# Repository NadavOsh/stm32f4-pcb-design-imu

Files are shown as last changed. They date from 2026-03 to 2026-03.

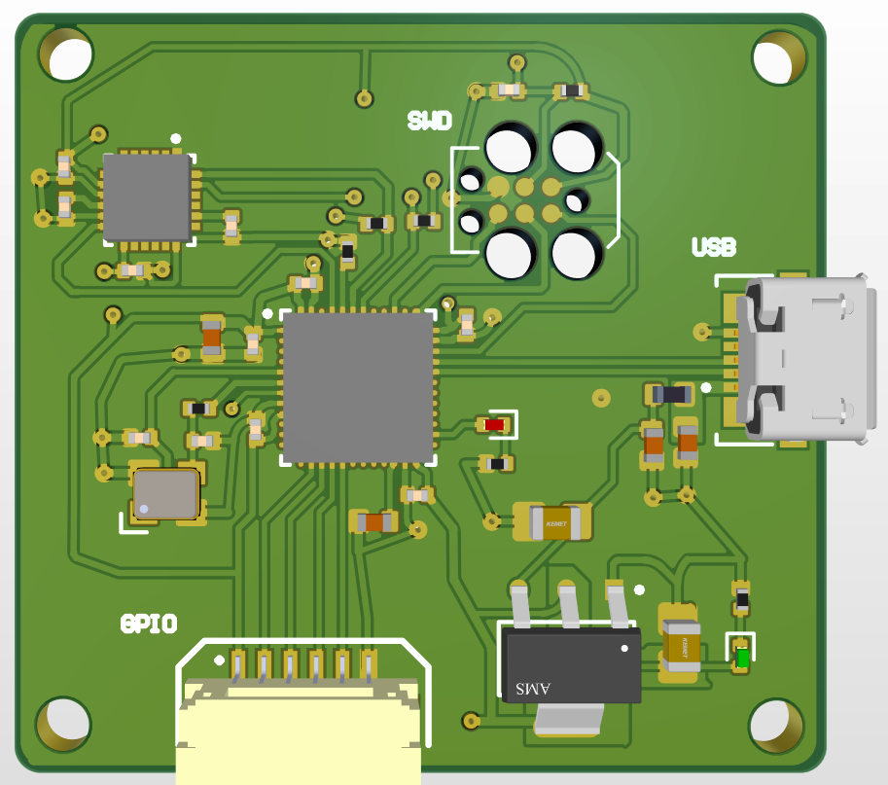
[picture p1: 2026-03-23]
Docs/STM32_PCB.png

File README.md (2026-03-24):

# stm32f4-pcb-design-imu
Custom STM32F4-based 4-layers PCB featuring MPU-6050 IMU, USB power, LDO regulation, and SWD debugging





# 1. Overview

This board is a custom embedded system built around the STM32F4 microcontroller, designed for motion sensing applications using an onboard IMU.

It includes:

* MCU: STM32F4 series (High-performance ARM Cortex-M4).

* Sensors: IMU MPU-6050 6-Axis Gyroscope & Accelerometer. Connected via I2C.

* Micro USB (Molex 473460001).
 
* Onboard AMS1117-3.3 LDO (5V to 3.3V regulation).

* JST-GH 6-pin (SM06B-GHS-TB) for external peripherals.

* Programming: Tag-Connect TC2030 (Plug-of-Nails™) SWD debugging interface.

* Configuration: BOOT0 hardwired to GND for normal flash boot.

# 2. Hardware Architecture

## Core Components:

## MCU: STM32F4 series
* IMU: MPU-6050 (accelerometer + gyroscope)

*Voltage Regulator: AMS1117-3.3 (5V → 3.3V)

*Clock Source: External 24 MHz oscillator

## Power System:
* Input: 5V via USB connector (473460001)
* Regulation: AMS1117-3.3 LDO
* Output: 3.3V rail powering MCU and peripherals

## Interfaces:
* USB
* SWD Debugging:
  * Connector: TC2030 Tag-Connect
  * Signals:
     * SWDIO
     * SWCLK
     * GND
    * 3.3V (reference)

## IMU Interface (MPU-6050):
* Communication: I2C
* Pull-up resistors: Present on SDA and SCL lines
* Powered from 3.3V rail

## Expansion Connector:
* JST 6-pin connector (SM06B-GHS-TB)
* Can be used for:
    * External sensors
    * UART / I2C / GPIO expansion

# 3. Boot Configuration:

* BOOT0 is tied to GND
   * MCU always boots from internal Flash
   * Prevents accidental boot into system bootloader

# 4. Clock Configuration:

* External 24 MHz oscillator connected to MCU

# 5. Pin Mapping

## Pin Mapping

| Function | MCU Pin | Direction | Description |
|---|---|---|---|
| I2C_SCL | PB6 | Bidir | I2C clock to MPU-6050 (pull-up) |
| I2C_SDA | PB7 | Bidir | I2C data to MPU-6050 (pull-up) |
| USB_VBUS | - | Input | 5V input from USB connector |
| USB_DN | PA11 | Bidir | USB differential data (-) |
| USB_DP | PA12 | Bidir | USB differential data (+) |
| SWDIO | PA13 | Bidir | SWD debug data |
| SWCLK | PA14 | Bidir | SWD debug clock |
| SW0 | PB3 | Bidir | Serial Wire Output. Debug |
| LED | PB13 | Output | Red LED |
| NRST | NRST | Input | MCU negative reset |
| BOOT0 | BOOT0  | Input | Boot configuration (Flash mode) |
| HSE_IN | PH0 | Input | External 24 MHz oscillator input |
| HSE_OUT | PH1 | Output | External oscillator output |
| 3V3 | — | Power | Regulated 3.3V rail |
| GND | — | Ground | Ground |
| JST_PIN_1 | - | Power | 3.3V |
| JST_PIN_2 | PA4 | I/O | Expansion connector |
| JST_PIN_3 | PA5 | I/O | Expansion connector |
| JST_PIN_4 | PA6 | I/O | Expansion connector |
| JST_PIN_5 | PA7 | I/O | Expansion connector |
| JST_PIN_6 | - | GND | GND |

# 6. Design Notes / Decisions

* Used I2C with pull-ups for reliable communication with IMU
* BOOT0 tied low for stable boot behavior
* Tag-Connect reduces connector footprint vs standard headers

# 7. Limitations / Future Improvements

* AMS1117 has high dropout and poor efficiency → consider switching regulator
* No ESD protection on USB

# 8. Files Included
* Schematic (PDF)
* PCB layout
* BOM
* Gerber Files
* Pick and Place

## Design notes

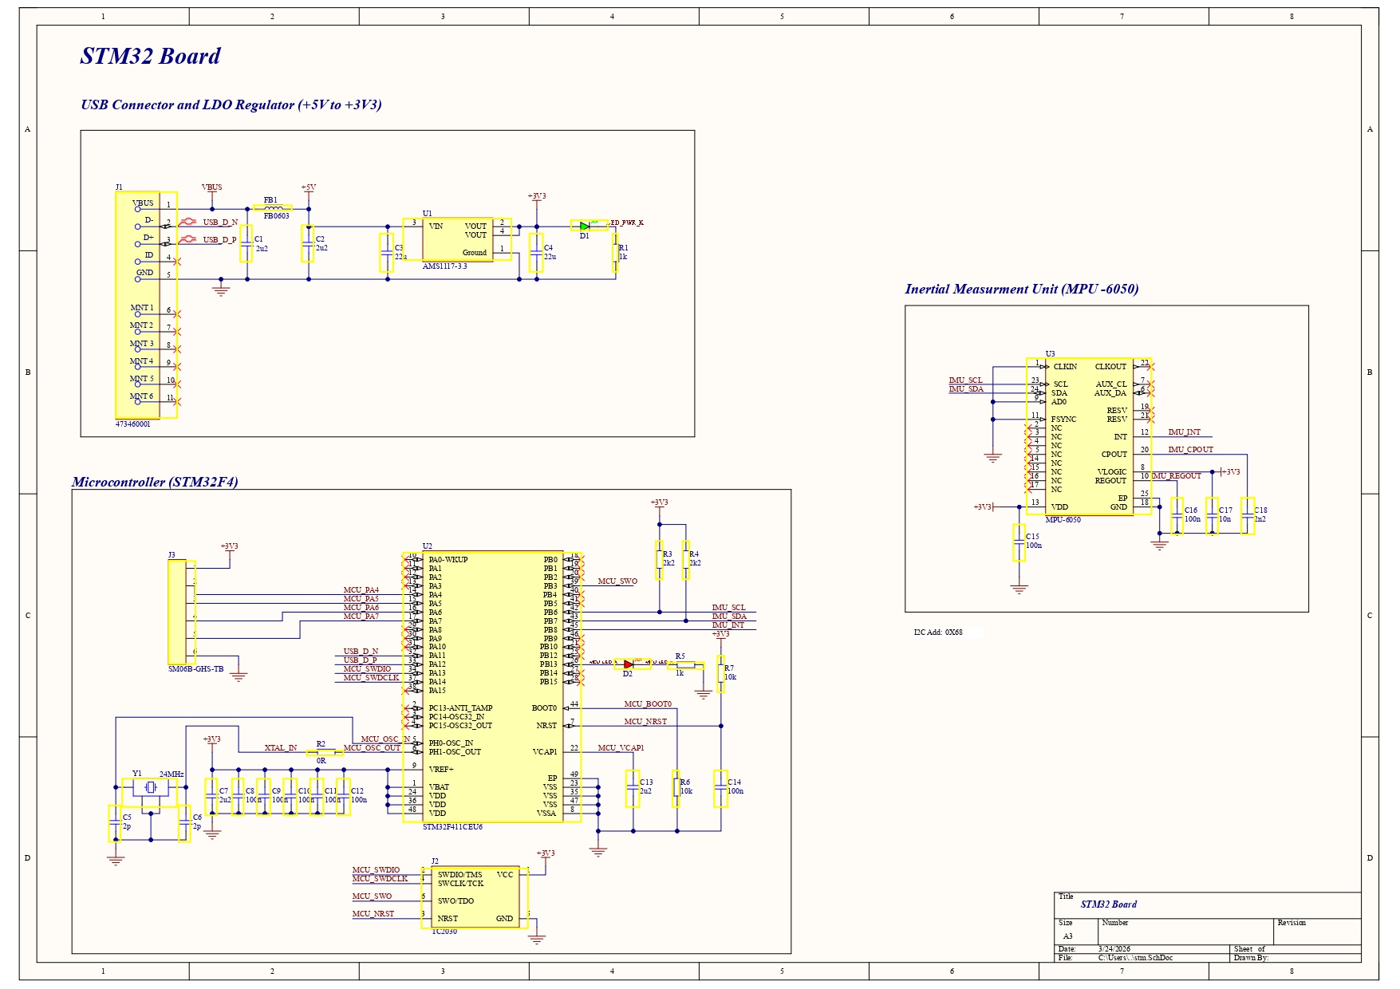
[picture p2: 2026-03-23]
Docs/STM32_Schematic_img.jpg

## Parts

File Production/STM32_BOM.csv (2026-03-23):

Comment | Description | Designator | Footprint | LibRef | Quantity
2u2 | Capacitor SMD 0603 | C1, C2, C7, C13 | CAP_0603 | CAP_0603 | 4
22u | Capacitor SMD 0805 | C3, C4 | CAP_0805 | CAP_0805 | 2
2p | Capacitor SMD 0402 | C5, C6 | CAP_0402 | CAP_0402 | 2
100n | Capacitor SMD 0402 | C8, C9, C10, C11, C12, C14, C15, C16 | CAP_0402 | CAP_0402 | 8
10n | Capacitor SMD 0402 | C17 | CAP_0402 | CAP_0402 | 1
2n2 | Capacitor SMD 0402 | C18 | CAP_0402 | CAP_0402 | 1
GREEN | LED 0402 GREEN SMD | D1 | LED_0402_GREEN | LED_0402_GREEN | 1
RED | LED 0402 RED SMD | D2 | LED_0402_RED | LED_0402_RED | 1
FB0603 | Ferrite Bead SMD 0603 | FB1 | FB_0603 | FB_0603 | 1
473460001 | CONN RCPT USB2.0 MICRO B SMD R/A | J1 | FP-473460001-MFG | CMP-2000-05246-2 | 1
SM06B-GHS-TB | Header Connector 6 Position 1.25MM Pitch SMD Horizontal JST GH | J3 | SM06B-GHS-TB | SM06B-GHS-TB | 1
1k | Resistor SMD 0402 | R1, R5 | RES_0402 | RES_0402 | 2
0R | Resistor SMD 0402 | R2 | RES_0402 | RES_0402 | 1
2k2 | Resistor SMD 0402 | R3, R4 | RES_0402 | RES_0402 | 2
10k | Resistor SMD 0402 | R6, R7 | RES_0402 | RES_0402 | 2
AMS1117-3.3 | LDO Voltage Regulators 1A, 3.3V | U1 | FP-AMS1117-IPC_C | CMP-209535-000001-1 | 1
STM32F411CEU6 | ARM Cortex-M4 32-bit MCU+FPU, 512 KB Flash, 128 KB RAM, 36 I/Os, 48-Pin UFQFPN, -40 to 85 degC, Tray | U2 | STM-UFQFPN48_L | CMP-0243-00165-1 | 1
MPU-6050 | 3-Axis Gyroscope, Accelerometer and a Digital Motion Processor(TM) (DMP), 2.375 to 3.46 V, -40 to 85 degC, 24-Pin QFN, RoHS, Tape and Reel | U3 | IS-QFN-24_V | CMP-1753-00002-2 | 1
24MHz | Crystal SMD 24MHz 10PPM 7pF 3225 | Y1 | XTAL_3225 | TSX-3225_24.0000MF15X-AC | 1

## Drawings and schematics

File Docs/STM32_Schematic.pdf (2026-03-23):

## USB Connector and LDO Regulator (+5V to +3V3)

# STM32 Board

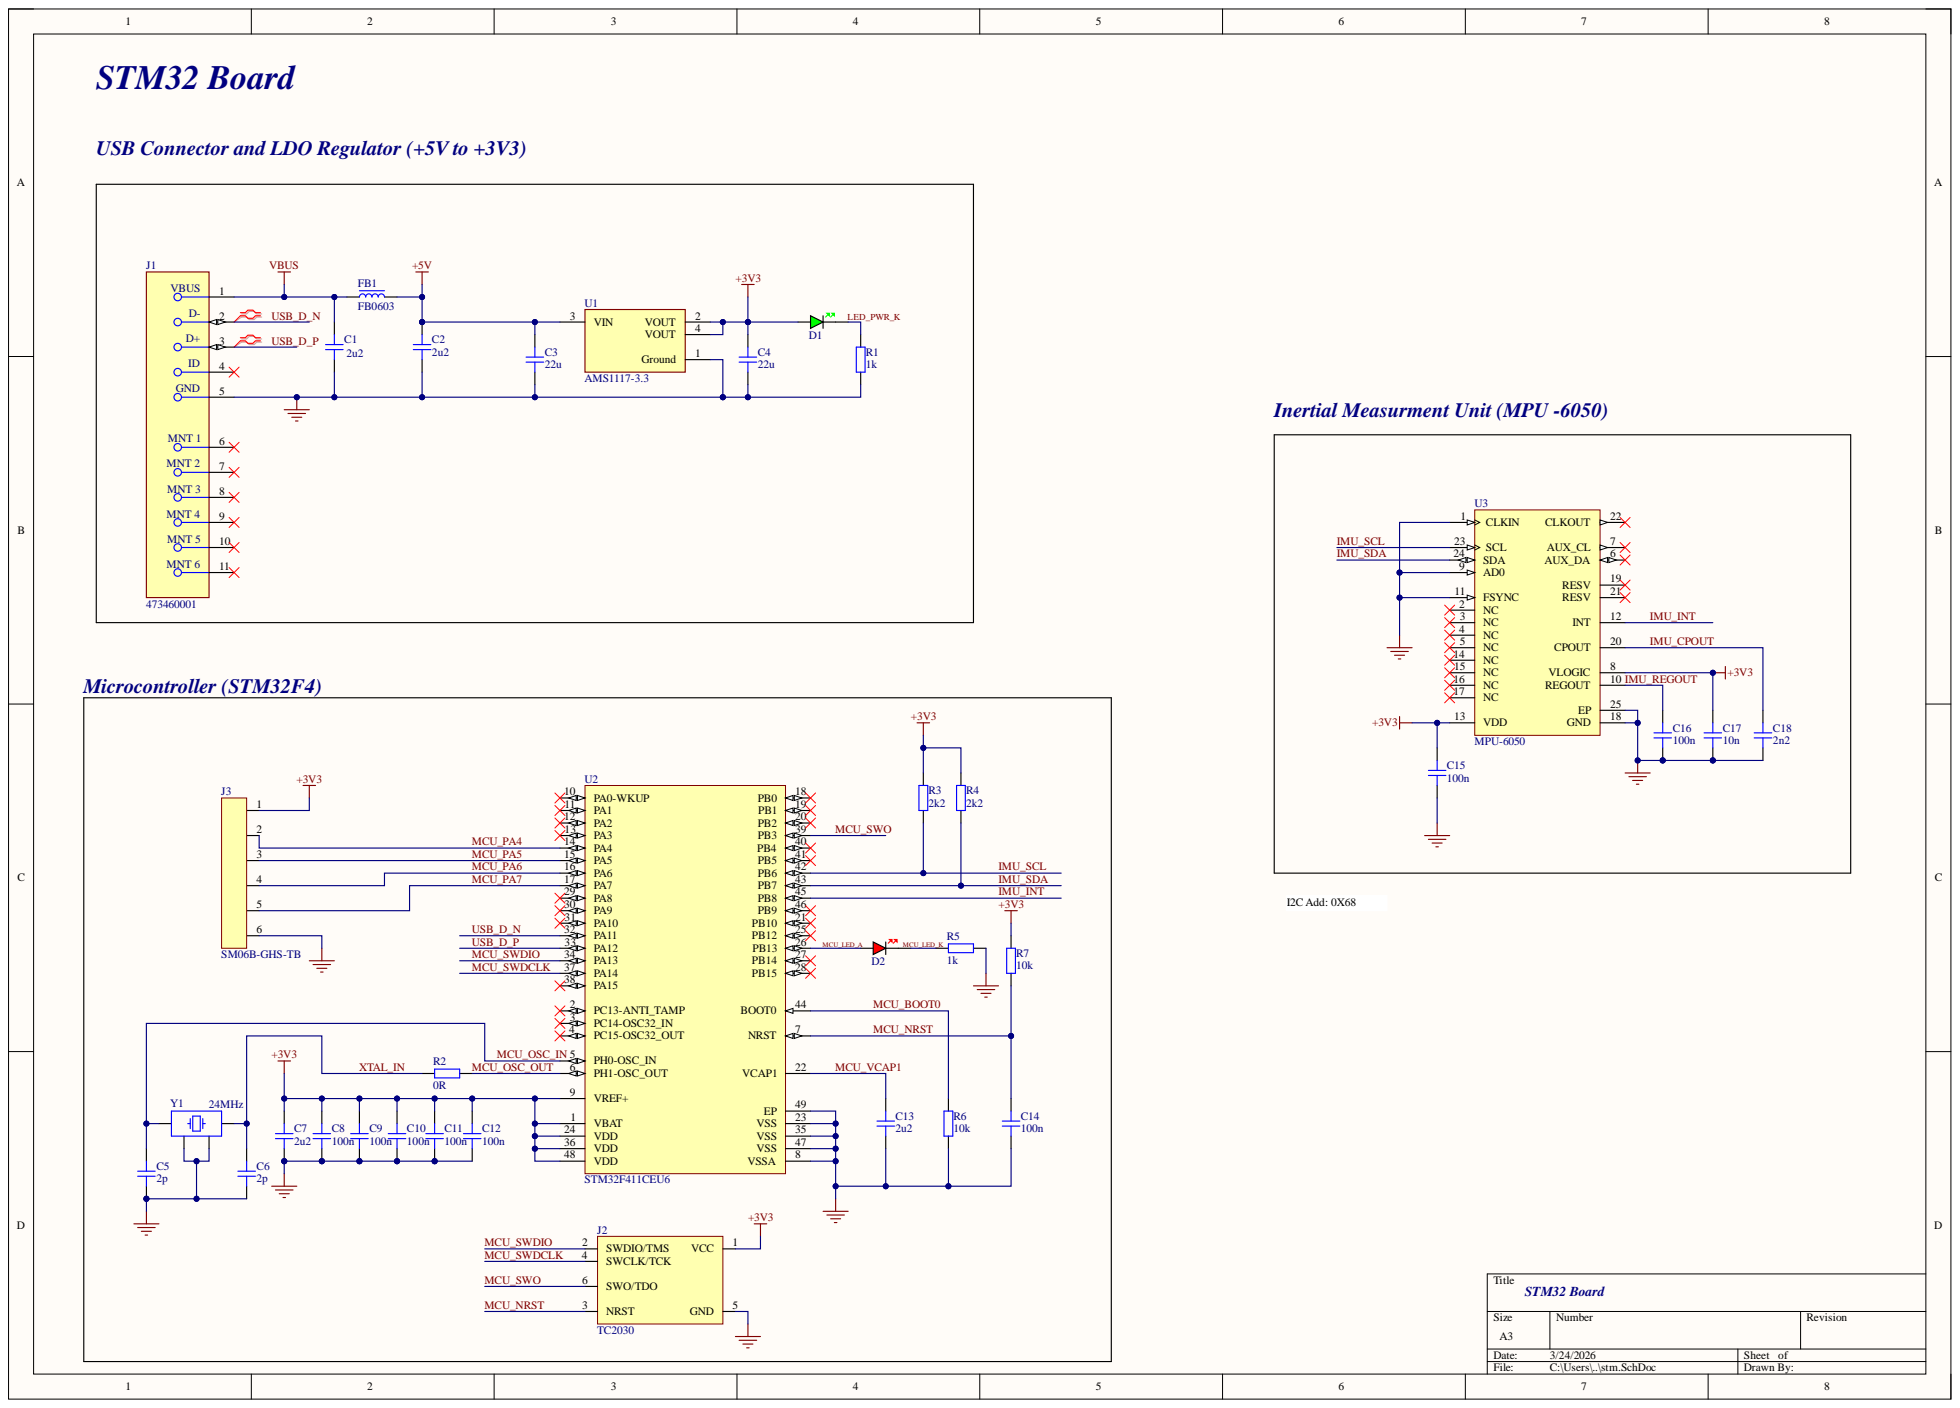
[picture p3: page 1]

Inertial Measurment Unit (MPU -6050)
